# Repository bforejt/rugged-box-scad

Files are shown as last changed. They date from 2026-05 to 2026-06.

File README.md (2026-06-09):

# rugged-box-scad

Parametric, customizable rugged storage box for OpenSCAD, with a
Gridfinity-compatible variant. Forked from
[smkent/monoscad](https://github.com/smkent/monoscad) to add
non-standard Gridfinity cell sizes and stand-on-back feet.

## Project status

This is a **shared personal project** and is **work in progress**. It
is not exhaustively tested — only a small number of parameter
combinations have been exported to STL and test-printed (those that
have, have printed successfully). Many permutations of the parametric
options have never been generated, sliced, or printed.

**Caution before printing.** This fork modifies the original
`smkent/monoscad` source (see [CHANGES.md](CHANGES.md)) and bumps the
[`kennetek/gridfinity-rebuilt-openscad`](https://github.com/kennetek/gridfinity-rebuilt-openscad)
library to a newer API than upstream monoscad targets. If you customize
the box for your own use case, render it carefully and inspect the
geometry before committing filament to it.

**Testing environment.** Rendering and validation is done on Apple
silicon (macOS) with OpenSCAD **2026.06.06 (git 49366181)**. Going
forward, the latest OpenSCAD on macOS will be the primary testing
environment used by the author. Other operating systems, processor
architectures, or older OpenSCAD versions may work fine — or may not
— but they aren't actively tested.

**Reporting issues — please include repeatability details.** Issue
reports are very welcome! To help investigate effectively, please
include enough detail to reproduce what you saw. At a minimum:

- **Customizer settings used** — a screenshot of the customizer
  panel, the saved parameter-set JSON, or just a list of which values
  you changed from the file defaults
- **OpenSCAD version** — Help → About inside the app (include the
  build / git hash if shown)
- **Operating system and architecture** — e.g. "Ubuntu 24.04 on
  x86_64" or "Windows 11 on ARM"
- **What you observed** — short summary of the problem (preview
  rendered differently than expected? slicer rejected the STL? a
  printed part didn't fit?)
- **Helpful extras** — the rendered STL, a screenshot of the
  OpenSCAD preview, or the slicer's error pane all speed things up

The more reproducible the report, the faster it can be looked into.
PRs are also welcome.

## Examples

Tested, printed parameter combinations live in [`examples/`](examples/),
one subdirectory per configuration with the exported STLs alongside.
Today this is one configuration —
[`examples/43mm_gridfinity_4x3`](examples/43mm_gridfinity_4x3/) — and
the list will grow as more variants are validated. Use these as
starting points if you want a known-good configuration rather than
generating from the SCAD yourself.

Two top-level designs in [`src/`](src/):

- [`rugged-box.scad`](src/rugged-box.scad) — standalone parametric box
- [`rugged-box-gridfinity.scad`](src/rugged-box-gridfinity.scad) —
  Gridfinity-compatible variant; bottom is a Gridfinity baseplate, top
  optionally exposes Gridfinity stacking lips
- [`rugged-box-library.scad`](src/rugged-box-library.scad) — shared
  library implementing both

### Compatible Gridfinity bins

The author's primary use case for the Gridfinity variant is filling
the box with bins generated from
[ostat/gridfinity_extended_openscad](https://github.com/ostat/gridfinity_extended_openscad).
In test prints those bins have mated correctly with the box's bottom
baseplate and (when enabled) the lid's stacking-lip surface — so if
you want a known-good source for bins to drop in, that's the
companion project that's been tried here.

## Setup

```sh
git clone --recurse-submodules https://github.com/<you>/rugged-box-scad.git
# or, if already cloned without --recurse-submodules:
git submodule update --init --recursive
```

Use a recent OpenSCAD — the latest release or development snapshot is
what the author tests against (see *Testing environment* above for the
exact build). Open any `.scad` file in [`src/`](src/) directly —
relative `use`/`include` paths resolve to the submodule under
[`lib/`](lib/), so no `OPENSCADPATH` setup is needed.

## License & attribution

This project is a derivative work of two upstream projects with
different licenses. The combined work is distributed under
**CC BY-SA 4.0** ([LICENSE](LICENSE)), as required by the upstream
rugged-box code.

| Source | License | Pinned commit |
| --- | --- | --- |
| [smkent/monoscad](https://github.com/smkent/monoscad) (rugged-box and gridfinity/rugged-box subdirs) | CC BY-SA 4.0 | [`a980c0e`](https://github.com/smkent/monoscad/commit/a980c0e4a83d43316286d994b0bda67a6889529a) |
| [kennetek/gridfinity-rebuilt-openscad](https://github.com/kennetek/gridfinity-rebuilt-openscad) (submodule at [`lib/gridfinity-rebuilt-openscad`](lib/gridfinity-rebuilt-openscad)) | MIT — see [LICENSES/MIT-gridfinity-rebuilt.txt](LICENSES/MIT-gridfinity-rebuilt.txt) | [`910e22d`](https://github.com/kennetek/gridfinity-rebuilt-openscad/commit/910e22d8607fd7f5f51ad5e5cbc5287a76810bfd) |

The MIT submodule is one-way compatible into CC BY-SA 4.0; the same
arrangement is used by the upstream monoscad repo.

Original rugged-box design by Stephen Kent (smkent / bulbasaur0 on
Printables). Gridfinity-rebuilt library by Kenneth Hodson (kennetek),
based on the original Gridfinity system by Zack Freedman.

## A note on slicer warnings (cosmetic)

Slicers (PrusaSlicer, OrcaSlicer, etc.) will report **hundreds of
"errors" or "facets fixed"** when loading the exported STLs. These are
**cosmetic** and do not affect the printed result.

Two patterns produce the count:

1. **Boolean tessellation noise** — OpenSCAD's CGAL/Manifold engines
   emit a small number of zero-area (degenerate) triangles wherever
   boolean operations create coincident vertices. Every part exported
   from this project shows roughly 400 of these as a baseline; the
   exact count varies with geometry.
2. **Coplanar surface duplicates** — when two unioned solids have
   faces sitting exactly on the same plane (rather than overlapping by
   a small epsilon), the surface gets tessellated twice. This shows up
   as a handful of duplicate facets, usually on lid-mating or
   seal-groove regions.

The exported meshes are **manifold and closed** (no open edges, no
non-manifold edges) — only the degenerate/duplicate facets show up,
which every slicer auto-removes silently before slicing. The error
count is the slicer telling you what it cleaned up, not a problem with
the model.

If the count bothers you, use the slicer's built-in repair (PrusaSlicer:
right-click → *Fix through Netfabb*) to write a clean STL.

## Modifications

This is a derivative work. All modifications relative to the upstream
sources are recorded in [CHANGES.md](CHANGES.md). Entries that may be
worth contributing back to upstream are tagged `[upstream-candidate]`.

Copyright © 2026 Brian Forejt, in addition to the original copyrights
of the upstream authors.

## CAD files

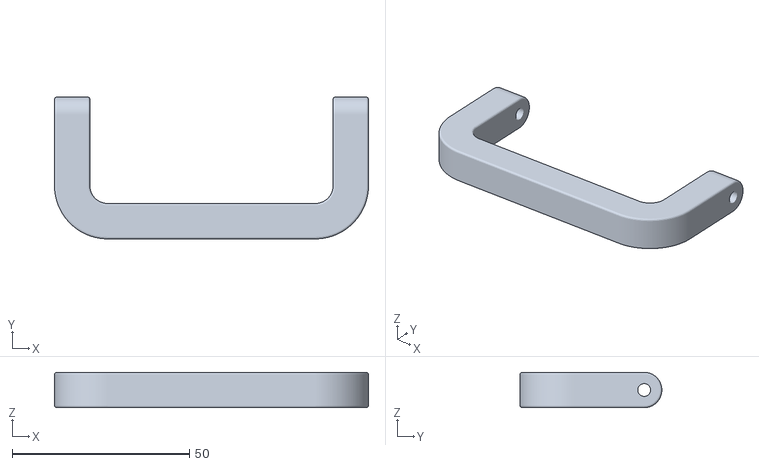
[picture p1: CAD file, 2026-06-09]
examples/43mm_gridfinity_4x3/rugged-box-gridfinity-handle.stl
88.6 x 40.0 x 10.0

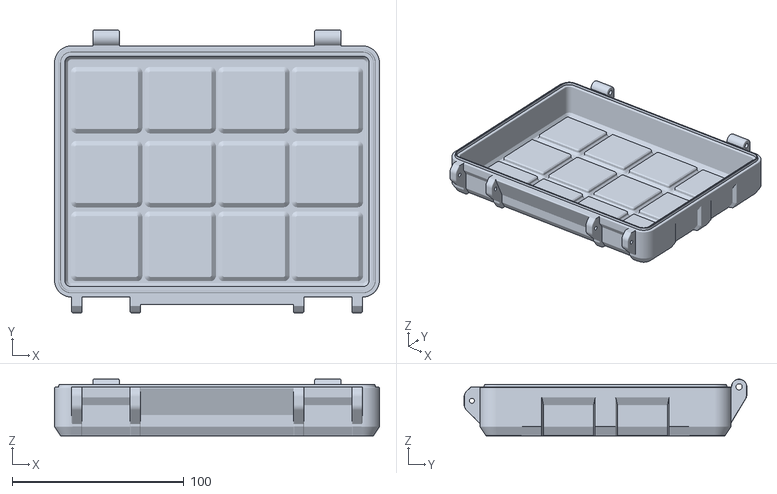
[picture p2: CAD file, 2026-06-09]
examples/43mm_gridfinity_4x3/rugged-box-gridfinity-4x3x6x3-top.stl
189.0 x 164.4 x 33.0

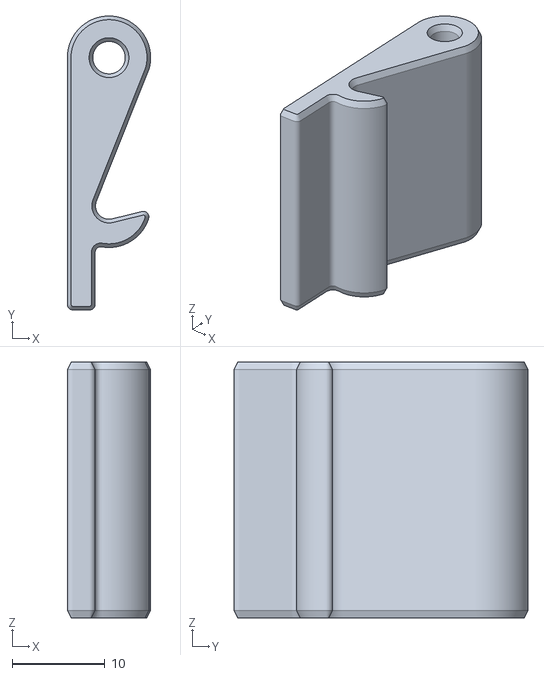
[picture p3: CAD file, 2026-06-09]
examples/43mm_gridfinity_4x3/rugged-box-gridfinity-4x3x6x3-latchx2.stl
9.00 x 31.7 x 27.6

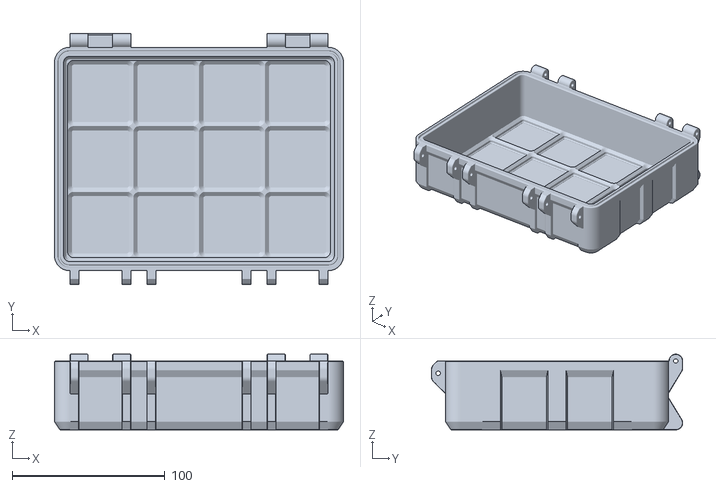
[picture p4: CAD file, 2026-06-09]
examples/43mm_gridfinity_4x3/rugged-box-gridfinity-4x3x6x3-bottom_w_handle.stl
189.0 x 164.4 x 49.5

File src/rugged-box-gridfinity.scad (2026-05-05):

/*
 * Gridfinity Rugged Storage Box, Parametric and Customizable
 * By smkent (GitHub) / bulbasaur0 (Printables)
 *
 * Licensed under Creative Commons (4.0 International License) Attribution-ShareAlike
 */

include <rugged-box-library.scad>;
include <../lib/gridfinity-rebuilt-openscad/src/core/standard.scad>;
use <../lib/gridfinity-rebuilt-openscad/gridfinity-rebuilt-baseplate.scad>;
use <../lib/gridfinity-rebuilt-openscad/src/core/base.scad>;
use <../lib/gridfinity-rebuilt-openscad/src/core/gridfinity-rebuilt-holes.scad>;
use <../lib/gridfinity-rebuilt-openscad/src/helpers/shapes.scad>;

/* [Rendering] */
// Part selection. Note: Assembled box previews show latches without chamfers for performance reasons.
Part = "assembled_open"; // ["bottom": Bottom, "top": Top, "latch": Latch, "stacking_latch": Stacking latch, "handle": Handle, "label": Label, "side-by-side": Top and Bottom side-by-side, "assembled_open": Assembled open, "assembled_closed": Assembled closed, "bottom_modifier": Bottom print modifier volume for attachment ribs, "top_modifier": Top print modifier volume for attachment ribs, "top_grid_modifier": Top print modifier volume for Gridfinity lid]

/* [Dimensions] */
// Interior side-to-side size in 42mm Gridfinity units
Width = 4; // [1:1:10]

// Interior front-to-back size in 42mm Gridfinity units
Length = 2; // [1:1:10]

// Interior bottom height in 7mm Gridfinity units
Bottom_Height = 7; // [1:1:30]

// Interior top height in 7mm Gridfinity units
Top_Height = 2; // [1:1:10]

/* [Gridfinity Features] */
Gridfinity_Base_Style = "minimal"; // [minimal: No magnet holes with minimal thickness, thick: No magnet holes but with magnet hole base thickness, enabled: Magnet holes with skeletonized baseplate, enabled_full: Magnet holes with filled baseplate]

// Add Gridfinity base stacking plates to outside of box top and bottom. Requires supports to print.
Gridfinity_Stackable = true;

// Side length of each square Gridfinity grid cell in millimeters (standard is 42)
Cell_Size = 42; // [30:0.5:50]

/* [Features] */
// Type or shape of seal to use, if desired
Lip_Seal_Type = "wedge"; // [none: None, wedge: Wedge ▽, square: Square □, "filament-1.75mm": 1.75mm Filament ○]

// Make the corners as thick as the box lip
Reinforced_Corners = true;

// Add a front grip to the box top (for boxes with two latches)
Top_Grip = true;

// Add end stops to the hinges on the box bottom
Hinge_End_Stops = true;

// Add feet at the bottom-back of the box bottom matching the hinge protrusion so the box can stand upright on its back when closed
Stand_On_Back = false;

// Add stacking latches and attachment points to the sides of the box
Stacking_Latches = true;

// Latch style
Latch_Type = "draw"; // [clip: Clip, draw: Draw]

// Add a third hinge for boxes 5U or wider
Third_Hinge = true;

// Optional handle for sufficiently wide boxes
Handle = true;

// Optional label for sufficiently wide boxes
Label = true;

// Custom text for optional label
Label_Text = "Label";

// Approximate height of text for optional label in millimeters
Label_Text_Size = 10; // [5:0.1:25]

/* [Advanced Size Adjustments] */
// Base wall thickness in millimeters for most of the box
Wall_Thickness = 3.0; // [2.4:0.1:10]

// Thickness in millimeters to add to the wall thickness for the box lip
Lip_Thickness = 3.0; // [0.4:0.1:10]

// Base thickness in millimeters of the support ribs. The latch ribs are this thick, while the hinge and side ribs are twice this thick.
Rib_Width = 6; // [1:0.1:20]

// Latch width in millimeters
Latch_Width = 28; // [5:1:50]

// Distance in millimeters between the latch hinge and catch screws which determines the latch vertical size
Latch_Screw_Separation = 16; // [5:1:40]

// Width in millimeters subtracted from latches for fit
Size_Tolerance = 0.20; // [0:0.01:1]

module __end_customizer_options__() { }

// Constants

edge_chamfer_proportion = 0.95;

border = 5;
gridfinity_height_increment = 7;

width = Width * Cell_Size + border;
length = Length * Cell_Size + border;
bottom_height = (
    Bottom_Height * gridfinity_height_increment
    + gridfinity_base_extra_height(hole=true)
);
top_height = Top_Height * gridfinity_height_increment + STACKING_LIP_HEIGHT;

corner_radius = BASE_TOP_RADIUS;

stackable_plate_offset = 3.4;
stackable_top_plate_offset = -0.8;
stackable_bottom_base_offset = -0.6;
top_base_offset = -(BASE_HEIGHT - STACKING_LIP_HEIGHT);

stacking_separation = Gridfinity_Stackable ? 1.6 : 0;

// Library overrides

function rb_color(part) = (part == "top" ? "LightSteelBlue" : "SteelBlue");

function rb_side_rib_positions() = [
    for (j = [for (i = [0:1:Length - 1]) i * Cell_Size])
    j - (Cell_Size * (Length / 2 - 0.5))
];

function rb_rear_rib_positions() = [
    for (j = [for (i = [1:1:Width - 2]) i * Cell_Size])
    j - (Cell_Size * (Width / 2 - 0.5))
];

function rb_latch_hinge_position() = (Cell_Size * (Width / 2 - 0.5));

function rb_stacking_latch_positions() = (
    Stacking_Latches
    ? [
        let (points = [
            each for (j = [
                for (i = [0:2:Length / 2 - 1]) i
            ]) (j == Length - 2 - j) ? [j] : [j, Length - 2 - j]
        ])
        for (j = [for (i = points) (i + 0.5) * Cell_Size])
        j - (Cell_Size * (Length / 2 - 0.5))
    ]
    : []
);

// Functions

function gridfinity_base_plate_magnets_enabled() = (
    (Gridfinity_Base_Style != "minimal" && Gridfinity_Base_Style != "thick")
);

function gridfinity_base_plate_magnet_height() = (Gridfinity_Base_Style != "minimal");

function gridfinity_base_plate_style() = (
    Gridfinity_Base_Style == "minimal"
        ? 0
        : Gridfinity_Base_Style == "thick"
            ? 1
            : Gridfinity_Base_Style == "enabled"
                // Use full plate instead of skeletonized for stackable top baseplate
                ? ($b_part == "top" ? 1 : 2)
                : Gridfinity_Base_Style == "enabled_full"
                    ? 1
                    : 0
);

function gridfinity_base_extra_height(hole) = (
    gridfinity_base_plate_magnet_height() ? (hole ? MAGNET_HOLE_DEPTH : 0) : 0
);

// Modules

module gridfinity_rectangle(adjust=0, height=BASE_HEIGHT * 2) {
    linear_extrude(height=height)
    rounded_square(
        [width + adjust, length + adjust],
        BASE_TOP_RADIUS,
        center=true
    );
}

function gridfinity_hole_options() = bundle_hole_options(
    refined_hole=false,
    magnet_hole=gridfinity_base_plate_magnets_enabled(),
    screw_hole=false,
    crush_ribs=true,
    chamfer=true,
    supportless=false
);

module gridfinity_baseplate(expand=false) {
    extra_depth = gridfinity_base_extra_height(hole=true);
    render(convexity=4)
    intersection() {
        linear_extrude(height=Cell_Size + extra_depth)
        square([(Width + 1) * Cell_Size, (Length + 1) * Cell_Size], center=true);
        translate([0, 0, extra_depth])
        gridfinityBaseplate(
            [Width, Length],
            Cell_Size,
            [
                expand ? ((Width + 1) * Cell_Size) : 0,
                expand ? ((Length + 1) * Cell_Size) : 0
            ],
            gridfinity_base_plate_style(),
            gridfinity_hole_options(),
            0
        );
    }
}

module gridfinity_base(w=Width, l=Length, hole=false, off=0) {
    // Pre-refactor kennetek's gridfinityBase took an `off` parameter that
    // shrank/grew the base XY dimensions. The new API has no equivalent;
    // approximate by uniformly scaling XY (Z preserved). At Cell_Size=42,
    // off=-0.2 → scale factor 0.9952 — base radius shrinks by ~0.02mm.
    scale_xy = (Cell_Size + off) / Cell_Size;
    scale([scale_xy, scale_xy, 1])
    gridfinityBase(
        [w, l],
        [Cell_Size, Cell_Size],
        hole ? gridfinity_hole_options() : bundle_hole_options()
    );
}

module gridfinity_bottom_base(hole=false) {
    intersection() {
        translate([0, 0, BASE_HEIGHT])
        mirror([0, 0, 1])
        gridfinity_base(hole=hole);
        gridfinity_rectangle(adjust=1.6);
    }
}

module rbox_interior_base(height = BASE_HEIGHT * 2) {
    intersection() {
        rbox_interior(cut_height=height);
        rbox_for_interior()
        linear_extrude(height=height)
        square([width * 2, length * 2], center=true);
    }
}

module gridfinity_baseplate_cut() {
    render()
    difference() {
        rbox_interior_base();
        rbox_for_interior()
        gridfinity_baseplate(expand=true);
    }
}
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

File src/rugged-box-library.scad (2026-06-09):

/*
 * Customizable and Parametric Rugged Storage Box
 * By smkent (GitHub) / bulbasaur0 (Printables)
 *
 * Rugged storage box library
 *
 * Licensed under Creative Commons (4.0 International License) Attribution-ShareAlike
 */

module __end_customizer_options__() { }

// Constants

$fa = $preview ? $fa : 2;
$fs = $preview ? $fs / 2 : 0.2;

// Attachment screw diameter
screw_diameter = 3; // M3

// Decrease screw hole diameter just slightly for better thread-forming fit
screw_hole_diameter_size_tolerance = -0.1;

// Widen angle of box plain ribs
plain_ribs_angle = 8;

// Extra space between box body and hinge for clearance
hinge_extra_setback = 0.2; // [0:0.1:2]
hinge_size_tolerance = 0.1;

// Box top hinge screw eyelet position fit tolerance adjustment
top_hinge_eyelet_position_tolerance = 0.1;

// Screw eyelet diameter as a proportion of screw diameter
screw_eyelet_size_proportion = 3.0; // [1.5:0.1:5]

// Depth and maximum width of lip grip
top_grip_depth = 6;
top_grip_width = 100;

// Latch size
latch_edge_radius = 0.8;
latch_body_size_proportion = 3.0; // [1.5:0.1:5]

// Stacking latch size
stacking_latch_catch_offset = -10;
stacking_latch_grip_length = 8;
stacking_latch_screw_separation = 20;

// Handle size
handle_thickness = 10;
handle_min_height = 16;
handle_max_height = 35;
handle_radius = 5;

// Label size
label_thickness = 2;
label_fit_thickness = 0.1;
label_text_thickness = 2.0;
label_holder_inset = 5;
label_holder_lip = 2;
label_holder_thickness = 2 + label_thickness + label_fit_thickness;
label_max_height = 30;

// Public modules

/*
 * Setup module
 *
 * Use this module to configure box sizing and features before rendering a part
 *
 * Arguments:
 *  - width: Interior side-to-side size
 *  - length: Interior front-to-back size
 *  - top_height: Interior top height
 *  - bottom_height: Interior bottom height
 *  - corner_radius: Interior corner radius (Reduces interior storage space)
 *  - edge_chamfer_proportion: Proportion of corner_radius to chamfer outer
 *    top/bottom edges (Reduces interior storage space)
 *  - lip_seal_type: Type of shape of seal to use, if desired:
 *      - "none": No seal
 *      - "wedge": Wedge-shaped seal
 *      - "square": Square-shaped seal
 *      - "filament-1.75mm": Seal cutout on both top and bottom for
 *          1.75mm filament
 *  - reinforced_corners: Make the corners as thick as the box lip
 *  - latch_type: Style of front latches: "clip" or "draw"
 *  - latch_count: Number of latches (1 or 2). The default of 0 determines the
 *    number of latches automatically.
 *  - top_grip: Add optional grip to front of box top
 *  - hinge_end_stops: Add optional hinge end stops to box bottom hinges
 *  - stand_on_back: Add feet to the bottom-back of the box bottom matching
 *    the hinge protrusion so the closed box can stand upright on its back
 *  - handle: Add optional handle for sufficiently wide boxes
 *  - label: Add optional label for sufficiently wide boxes
 *  - label_text: Custom text for optional label
 *  - label_text_size: Approximate label text size in millimeters
 *
 * Example:
 *
 *      box(width=100, length=50, top_height=15, bottom_height=30) {
 *          // Render box top
 *          translate([120, 0, 0])
 *          rbox_top();
 *
 *          // Render box bottom
 *          rbox_bottom();
 *      }
 */
module rbox(
    width,
    length,
    bottom_height=0,
    top_height=0,
    corner_radius=5,
    edge_chamfer_proportion=0.4,
    lip_seal_type="wedge",
    reinforced_corners=false,
    latch_type="draw",
    latch_count=0,
    top_grip=false,
    hinge_end_stops=false,
    stand_on_back=false,
    handle=false,
    label=false,
    label_text="",
    label_text_size=10
) {
    // Set base dimensions
    $b_inner_width = width;
    $b_inner_length = length;
    $b_top_inner_height = top_height;
    $b_bottom_inner_height = bottom_height;
    $b_corner_radius = corner_radius;
    $b_edge_chamfer_proportion = edge_chamfer_proportion;
    $b_lip_seal_type = lip_seal_type;
    $b_reinforced_corners = reinforced_corners;
    $b_latch_type = latch_type;
    $b_latch_count = latch_count;
    $b_top_grip = top_grip;
    $b_hinge_end_stops = hinge_end_stops;
    $b_stand_on_back = stand_on_back;
    $b_handle = handle;
    $b_label = label;
    $b_label_text = label_text;
    $b_label_text_size = label_text_size;
    // Set defaults
    $b_preview_assembled = false;
    $b_preview_box_open = false;
    rbox_size_adjustments()
    _box_rib_angle(0)
    // Render modules
    children();
}

/*
 * Advanced size adjustments setup module
 *
 * Use this module to configure advanced box sizing adjustments before rendering a part
 *
 * Arguments:
 *  - wall_thickness: Base wall thickness for most of the box
 *  - lip_thickness: Thickness to add to the wall thickness for the box lip
 *  - rib_width: Base thickness of the support ribs. The latch ribs are this
 *    thick, while the hinge and side ribs are twice this thick.
 *  - latch_width: Latch side-to-side width
 *  - latch_screw_separation: Distance between the latch hinge and catch screws
 *    which determines the latch vertical size
 *  - latch_amount_on_top: Vertical size of the latch measured from the latch
 *    hinge screw hole overlapping the top of the box, with the remainder
 *    overlapping the bottom. Set to 0 to determine automatically.
 *  - third_hinge_width: Add a third, center hinge if the box's interior is at
 *    least as wide as this value. Set to 0 to disable (default).
 *  - stacking_separation: The vertical distance between two stacked boxes.
 *    Used for stacking latch attachment placement.
 *  - size_tolerance: Size subtracted from latch and upper hinge widths for fit
 *
 * Example:
 *
 *      box(width=100, length=50, top_height=15, bottom_height=30) {
 *          rbox_size_adjustments(wall_thickness=3.0, lip_thickness=3.0) {
 *              // Render box top
 *              translate([120, 0, 0])
 *              rbox_top();
 *
 *              // Render box bottom
 *              rbox_bottom();
 *          }
 *      }
 */
module rbox_size_adjustments(
    wall_thickness=2.4,
    lip_thickness=2.0,
    rib_width=4.0,
    latch_width=22,
    latch_screw_separation=20,
    latch_amount_on_top=0,
    third_hinge_width=0,
    stacking_separation=0,
    size_tolerance=0.05
) {
    $b_wall_thickness = wall_thickness;
    $b_lip_thickness = lip_thickness;
    $b_rib_width = rib_width;
    $b_size_tolerance = size_tolerance;
    $b_latch_width = latch_width;
    $b_latch_screw_separation = latch_screw_separation;
    $b_latch_amount_on_top = _init_latch_amount_on_top(latch_amount_on_top);
    $b_third_hinge_width = third_hinge_width;
    $b_stacking_separation = stacking_separation;
    // Set computed values
    $b_total_lip_thickness = wall_thickness + lip_thickness;
    $b_lip_height = lip_thickness * 2;
    $b_edge_radius = wall_thickness / 5;
    // Set dependent values
    $b_top_outer_height = $b_top_inner_height + wall_thickness;
    $b_bottom_outer_height = $b_bottom_inner_height + wall_thickness;
    $b_outer_width = $b_inner_width + $b_total_lip_thickness * 2;
    $b_outer_length = $b_inner_length + $b_total_lip_thickness * 2;
    $b_curved_inner_width = $b_inner_width + $b_edge_radius * 2;
    $b_curved_inner_length = $b_inner_length + $b_edge_radius * 2;
    $b_outer_chamfer_horizontal = $b_edge_chamfer_proportion * $b_corner_radius;
    $b_outer_chamfer_vertical = $b_outer_chamfer_horizontal * 1.5;
    $b_hinge_screw_offset = _attachment_screw_offset();
    $b_latch_screw_offset = _attachment_screw_offset();
    children();
}

// Part modules

module rbox_top() { _box_part_setup("top") { rbox_body(); children(); } }
module rbox_bottom() { _box_part_setup("bottom") { rbox_body(); children(); } }

module rbox_for_top() { _box_part_setup("top") children(); }
module rbox_for_bottom() { _box_part_setup("bottom") children(); }

module rbox_for_interior() { translate([0, 0, $b_wall_thickness]) children(); }

module rbox_latch(placement="print") { _latch(placement); }

module rbox_stacking_latch(placement="print") { _stacking_latch(placement); }

module rbox_handle(placement="print") { _handle(placement); }

module rbox_label(placement="print") {
    rbox_for_bottom() {
        _box_label(placement);
    }
}

module rbox_body() {
    _box_color()
    _box_body();
}

module rbox_top_modifier_volume() { _box_part_setup("top") { rbox_body_modifier_volume(); } }
module rbox_bottom_modifier_volume() { _box_part_setup("bottom") { rbox_body_modifier_volume(); } }

module rbox_body_modifier_volume() {
    _box_color()
    _box_body_modifier_volume();
}

module rbox_interior(cut_height=0) {
    _box_color()
    render(convexity=4) {
        _box_extrude()
        _box_interior_shape(cut_height);
        rbox_for_interior()
        _box_center_base($b_inner_height);
    }
}
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

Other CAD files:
src/rugged-box.scad

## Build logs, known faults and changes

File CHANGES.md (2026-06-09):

# Changes

Modifications to the upstream sources in this repo. Entries tagged
`[upstream-candidate]` describe changes that could plausibly be
contributed back to monoscad as a PR.

## Baselines

- **monoscad**: [smkent/monoscad@a980c0e](https://github.com/smkent/monoscad/commit/a980c0e4a83d43316286d994b0bda67a6889529a)
  (main as of 2026-05-03), specifically:
  - `rugged-box/rugged-box.scad`
  - `rugged-box/rugged-box-library.scad` (identical to
    `gridfinity/rugged-box/rugged-box-library.scad`; one copy retained)
  - `gridfinity/rugged-box/rugged-box-gridfinity.scad`
- **gridfinity-rebuilt-openscad**: [kennetek/gridfinity-rebuilt-openscad@910e22d](https://github.com/kennetek/gridfinity-rebuilt-openscad/commit/910e22d8607fd7f5f51ad5e5cbc5287a76810bfd)
  (2025-08-31). Initial import was pinned at `0b7bf6e` (2024-01-29)
  to match Stephen's original tested API; bumped to `910e22d` on
  2026-05-03 — see migration entry below.

## 2026-05-03 — Initial import

- Imported the three rugged-box sources listed above into `src/`.
- Submoduled `lib/gridfinity-rebuilt-openscad` at the pin above.
- Adjusted `include`/`use` paths in `src/rugged-box-gridfinity.scad`
  to reference `../lib/gridfinity-rebuilt-openscad/` (Stephen's
  originals assumed the library was at `OPENSCADPATH` or in a sibling
  `gridfinity-rebuilt-openscad/` directory).

### `[upstream-candidate]` Add `Stand_On_Back` parameter and stand-feet module

Adds an optional pair of feet at the bottom-back of the box bottom,
matching the hinge protrusion, so the closed box can stand upright on
its back edge.

- `src/rugged-box-library.scad` — new `stand_on_back` arg on the `rbox`
  module, plumbed through to a new `_box_stand_feet` module which uses
  a new `_box_stand_foot_body` helper. Wired into both `assembled_open`
  and `assembled_closed` previews.
- `src/rugged-box.scad` — `Stand_On_Back` customizer parameter passed
  to `rbox`.
- `src/rugged-box-gridfinity.scad` — same wiring on the Gridfinity
  variant.

### `[upstream-candidate]` Parameterize Gridfinity cell size

Adds a `Cell_Size` customizer parameter to the Gridfinity rugged-box
(default 42 mm, range 30–50 mm in 0.5 mm steps), replacing the
hardcoded `l_grid` constant from gridfinity-rebuilt-openscad. Allows
non-standard Gridfinity grids (e.g., metric-imperial hybrids,
shrunk/expanded layouts).

- `src/rugged-box-gridfinity.scad` — `Cell_Size` parameter; all
  `l_grid` references in dimension calculations, rib positioning,
  baseplate generation, and stacking-lip generation rebound to
  `Cell_Size`.

## 2026-06-07 — Documentation: project status, examples, slicer-warnings note

Three new `README.md` sections:

- **Project status** — flags this as a shared personal project and
  work-in-progress. Notes that only a small number of parameter
  combinations have been exported to STL and test-printed; cautions
  users to inspect customized geometry before printing, particularly
  given this fork's divergence from `smkent/monoscad` and use of a
  newer `kennetek/gridfinity-rebuilt-openscad` API; invites issue
  reports for untested permutations.
- **Examples** — points at [`examples/`](examples/) as the home for
  known-good tested STL combinations (currently
  [`43mm_gridfinity_4x3`](examples/43mm_gridfinity_4x3/)).
- **A note on slicer warnings (cosmetic)** — documents why slicers
  report hundreds of "facets fixed" / "errors" on the exported STLs.
  The meshes are manifold and closed (verified via edge-incidence
  analysis); the count is OpenSCAD CGAL/Manifold boolean-tessellation
  noise (~400 zero-area triangles baseline per part) plus a small
  number of coplanar surface duplicates. Slicers auto-clean both and
  the slice output is unaffected.

Also re-exported [`examples/43mm_gridfinity_4x3/rugged-box-gridfinity-4x3x6x3-top.stl`](examples/43mm_gridfinity_4x3/rugged-box-gridfinity-4x3x6x3-top.stl)
as ASCII (was binary) — the analysis comparing baseline tessellation
counts across parts used this re-export.

Follow-up: expanded the **Project status** section with a **Testing
environment** note (Apple silicon, OpenSCAD 2026.06.06 git 49366181,
macOS as primary target — other OSes / older OpenSCAD versions may
work but aren't actively tested) and turned the issue-reports
paragraph into a checklist of repeatability details (customizer
settings, OpenSCAD version, OS/arch, summary, optional STL/screenshot)
so reports come in with enough detail to investigate.

Follow-up 2: dropped the *"OpenSCAD 2021.01 or newer recommended"*
line in the Setup section in favor of a pointer to the latest release
/ development snapshot (we don't actively test older versions, so
recommending them was misleading). Added a **Compatible Gridfinity
bins** subsection noting that
[ostat/gridfinity_extended_openscad](https://github.com/ostat/gridfinity_extended_openscad)
is the bin-generating companion project the author uses; its bins
have mated correctly with this box's bottom baseplate and stacking
lid in test prints.

## 2026-05-06 — `[upstream-candidate]` Fix stand-foot floating slivers on short boxes

`_box_stand_foot_body` computed `rib_hull_height` from
`screw_eyelet_radius`, `wall_thickness`, `rib_width`, and
`corner_radius` — independent of box height. With default `Rib_Width=6`
that yields ~38 mm. `_box_attachment_rib_cut` only clips the
inside-the-wall zone up to `wall_thickness + outer_height`, so on
boxes shorter than that, the foot's rib-shape support column
overshoots the clipper and survives as floating slivers above the box
top. Most visible on small `Bottom_Height` values; subtler but still
present on default sizes.

The hinge body doesn't have this problem because it builds at
`outer_height` and mirrors downward, so any overshoot lands below
`z=0` where the second clipper catches it. The stand foot has no
analogous downward-mirror, so the symmetry breaks.

Fix: clamp `rib_hull_height` to `$b_outer_height` in
`_box_stand_foot_body`. The clamp only affects the structural support
column inside the box wall (which would have been clipped anyway on
tall boxes); the visible eyelet bulge at low Z is unaffected. With
`Stand_On_Back=false` the geometry is byte-identical to before.

- `src/rugged-box-library.scad` — single-line `min(..., $b_outer_height)`
  wrapper around the existing formula.

## 2026-05-05 — `[upstream-candidate]` End-stop bar follows stand-foot contour

When `Stand_On_Back=true` and `Hinge_End_Stops=true` are both enabled,
the end-stop bar between the hinges grows a foot-shaped protrusion at
its bottom so its contour matches the corner stand feet on either
side. The corner feet themselves are unchanged (still aligned with the
hinge ribs above). The result reads as one continuous arch across the
back wall: feet at the corners, end-stop in the middle, all merging
into a single wide protrusion at low Z, while the end-stop bar stays
narrow at higher Z. When `Stand_On_Back=false`, the end-stop bar is
exactly the existing geometry.

- `src/rugged-box-library.scad` — `_box_hinge_rib_bottom_end_stop`
  conditionally emits an additional `_box_stand_foot_body(width=width)`
  inside its rotated frame when `$b_stand_on_back` is true. Net diff
  from main: 7 lines added.

## 2026-05-03 — `[upstream-candidate]` Migrate to current kennetek API

Bumped the `lib/gridfinity-rebuilt-openscad` submodule from `0b7bf6e`
(Jan 2024) to `910e22d` (Aug 2025), and updated
`src/rugged-box-gridfinity.scad` to match the refactored kennetek API.

**Imports** — added direct imports for the relocated symbols:
- `include` of `standard.scad` now from `src/core/`
- new `use` of `src/core/base.scad` (was in `gridfinity-rebuilt-utility.scad`)
- new `use` of `src/core/gridfinity-rebuilt-holes.scad` for `bundle_hole_options`
- new `use` of `src/helpers/shapes.scad` for `rounded_square`

**Renamed constants:**
- `h_lip` → `STACKING_LIP_HEIGHT` (3.548 → 4.4 mm)
- `h_base` → `BASE_HEIGHT` (5 → 7 mm)
- `h_hole` → `MAGNET_HOLE_DEPTH` (2.4 mm, unchanged value)
- `r_base` → `BASE_TOP_RADIUS` (4 → 3.75 mm)

The base/lip dimension drift means the rendered Z-geometry of the
Gridfinity bottom and the lid's mating top base differ slightly from
the previous version. Both halves consistently use the new constants,
so they remain self-compatible.

**Function signatures:**
- `gridfinityBaseplate(W, L, l, dx, dy, sp, magnets, sh, fitx, fity)`
  → `gridfinityBaseplate([W, L], l, [dx, dy], sp, hole_options, sh, [fitx, fity])`
  with `magnets` boolean replaced by a `bundle_hole_options(...)` bundle.
- `gridfinityBase(gx, gy, l, dx, dy, style_hole, off=, …)`
  → `gridfinityBase([gx, gy], [l, l], hole_options, …)`. The `off`
  parameter is gone; replaced with a uniform XY `scale()` wrapper that
  reproduces the inset (`-0.2mm` at the one callsite that needs it).

**Module replacement:**
- `rounded_rectangle(w, l, h, r)` → `linear_extrude(h) rounded_square([w, l], r, center=true)`.

**New helper:**
- `gridfinity_hole_options()` — local function that produces the
  `bundle_hole_options(...)` bundle, factoring out shared options
  (`crush_ribs=true`, `chamfer=true`) so both call sites stay in sync.

**Verification:** every `Part` value (12 total) renders cleanly with no
OpenSCAD errors or warnings, across all four `Gridfinity_Base_Style`
options, with `Gridfinity_Stackable` on/off, with `Stand_On_Back`
on/off, and at non-standard `Cell_Size` values (30, 38, 50). Print fit
of the new stacking-lip / top-base interface has not yet been
physically verified.

## Future work

- **Print-fit verification of the migrated lid/base interface.**
  The lid's top base uses a `scale()` workaround in place of the old
  `gridfinityBase(off=-0.2)` 0.2 mm fit-tolerance inset. Behaviorally
  equivalent in CSG, but worth a printed test before declaring final.
- **Optionally expose `bundle_hole_options(...)` flags as customizer
  parameters** (refined holes, screw holes, supportless magnet pockets,
  thumbscrew bases). Currently `gridfinity_hole_options()` hardcodes
  `crush_ribs=true, chamfer=true` and disables the rest.

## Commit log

2026-05-04 Initial setup: forked rugged-box from smkent/monoscad@a980c0e
    Adds CC BY-SA 4.0 license, MIT license snapshot for the
    gridfinity-rebuilt-openscad submodule (pinned at 0b7bf6e),
    README, CHANGES, and .gitignore. Adjusts include paths in
    rugged-box-gridfinity.scad to reference the submodule via
    relative path.
    Initial src/ also contains two pre-existing local modifications
    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
    [rugged-box-gridfinity.scad, rugged-box-library.scad, rugged-box.scad]
2026-05-04 Migrate Gridfinity variant to current kennetek API
    Bumps lib/gridfinity-rebuilt-openscad from 0b7bf6e (Jan 2024) to
    910e22d (Aug 2025) and updates rugged-box-gridfinity.scad to match.
    - Constants renamed: h_lip → STACKING_LIP_HEIGHT, h_base → BASE_HEIGHT,
    h_hole → MAGNET_HOLE_DEPTH, r_base → BASE_TOP_RADIUS. Base/lip Z
    values shift slightly with the upstream spec; both halves use the
    new constants and remain self-compatible.
    - gridfinityBaseplate signature: positional args repacked into 2D
    vectors; magnets boolean replaced by bundle_hole_options(...).
    - gridfinityBase signature: 2D vectors; off= parameter is gone, replaced
    with a uniform XY scale() wrapper that reproduces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
    [rugged-box-gridfinity.scad]
2026-05-05 End-stop bar follows stand-foot contour when both are active
    Modify _box_hinge_rib_bottom_end_stop so when $b_stand_on_back is
    true, it emits an additional _box_stand_foot_body at its low-Z end
    (inside the same rotated frame). The new foot-shaped protrusion
    visually merges with the two corner stand feet on either side, so
    the bottom-back of the box reads as one continuous arch when both
    options are active. The end-stop bar above the foot region remains
    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
    [rugged-box-library.scad]
2026-05-09 Fix floating slivers on short boxes when Stand_On_Back is active
    _box_stand_foot_body computes rib_hull_height from screw and rib/wall
    thickness — independent of box height. On boxes with Bottom_Height
    smaller than ~25mm, the foot's rib-shape support column overshoots
    the rib_cut clipper and floating slivers survive above the box top.
    Clamp rib_hull_height to $b_outer_height. The clamp only affects the
    inside-the-wall structural column (which the rib_cut would clip on
    tall boxes anyway); the visible eyelet bulge at low Z is unaffected.
    Stand_On_Back=false renders byte-identically to main.
    [rugged-box-library.scad]
2026-06-07 Document project status, examples, and slicer-warning baseline
    Add three README sections:
    - Project status: shared personal project, work-in-progress, only a
    few parameter combinations test-printed, issues welcome. Notes that
    this fork modifies smkent/monoscad and uses a newer kennetek API
    than upstream targets, so users should inspect customized geometry
    before printing.
    - Examples: points at examples/43mm_gridfinity_4x3/ as the (currently
    only) known-good tested configuration.
    - Slicer-warnings note: explains why PrusaSlicer reports hundreds of
    "facets fixed" — cosmetic boolean-tessellation noise plus a small
    number of coplanar-surface duplicates, none of which affect the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
2026-06-07 Re-export top STL in ASCII for tessellation analysis
    ASCII format makes the file directly inspectable for per-triangle
    analysis (degenerate count, coplanar duplicates, edge-incidence
    checks). See the slicer-warnings note in README for what the analysis
    showed.
    [rugged-box-gridfinity-4x3x6x3-top.stl]
2026-06-07 CHANGES.md entry for the documentation updates
    Records the README sections added in 506034a (project status,
    examples, slicer-warnings note) and the ASCII re-export of the
    4x3x6x3 top STL.
2026-06-07 Document testing environment and structured issue-report request
    Add a Testing environment paragraph (Apple silicon, OpenSCAD
    2026.06.06 git 49366181, macOS as primary target — other OSes /
    architectures / older OpenSCAD versions not actively tested) and
    expand the issue-reports paragraph into a checklist of repeatability
    details (customizer settings, OpenSCAD version, OS/arch, observation
    summary, optional STL or screenshot).
    CHANGES.md follow-up note appended to the same-day documentation
    entry.
2026-06-07 Drop stale OpenSCAD-version recommendation, add compatible-bins note
    - Setup: replaced "OpenSCAD 2021.01 or newer recommended" with a
    pointer to the latest release / development snapshot. Older
    versions aren't actively tested, so calling out 2021.01 as the
    baseline was misleading.
    - Added "Compatible Gridfinity bins" subsection pointing at
    ostat/gridfinity_extended_openscad as the bin-generating companion
    project the author uses with the Gridfinity variant. Its bins have
    mated correctly with the box bottom baseplate and stacking lid in
    test prints.
    - CHANGES.md: appended a follow-up bullet under the 2026-06-07
    documentation entry covering both above.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
2026-06-09 Re-export latchx2 and handle STLs
    Latchx2 re-rendered (smaller binary STL); handle re-exported as ASCII
    to match the top STL format used for tessellation analysis.
    [rugged-box-gridfinity-4x3x6x3-latchx2.stl, rugged-box-gridfinity-handle.stl]
2026-06-09 First pass: squared-off lid hinge foot when Stand_On_Back is active
    Adds _box_hinge_top_stand_foot — a rectangular slab unioned with each
    lid hinge eyelet (only when $b_stand_on_back is true). The slab's
    outer face is co-planar with the eyelet cylinder's outermost tangent,
    so it doesn't change the hinge's outer protrusion distance, but it
    turns what was a curved point contact into a flat rectangular contact
    patch.
    When the closed box is laid on its back face, the slab face shares
    the floor load with the bottom's stand-on-back corner feet and the
    hinge no longer wobbles.
    When Stand_On_Back=false the lid geometry is byte-identical to main
    (regression-verified by STL MD5).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
    [rugged-box-library.scad]
2026-06-09 Replace squared block with back-face rib extension
    First pass put a horizontal squared slab below the lid eyelet — sat
    too far from the lid back face to act as the foot. Replace it with a
    vertical slab on the lid's back face at each hinge group, extending
    from the eyelet position up to the lid's outer-top Z. The slab's
    outer face is co-planar with the eyelet's outermost tangent, so it
    presents a flat strip of contact along the full lid-back height when
    the closed box is laid on its back. The hinge eyelet stays a rounded
    cylinder.
    sob=false CSG byte-identical to main (regression-verified).
    [rugged-box-library.scad]
2026-06-09 Lid stand-foot: merge to lid wall + add 45° chamfer at outer corner
    - Extend the slab's inner X past the lid back wall so it fuses with
    the existing rib_shape extrusion — eliminates the V-shaped notch
    between the slab and the lid body.
    - Add a 45° chamfer (size = 2 × $b_edge_radius) at the outer-bottom
    corner of each slab, mirroring the edge chamfers used elsewhere on
    the box's outer surfaces.
    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
    [rugged-box-library.scad]
2026-06-09 Lid stand-foot: replace 45° chamfer with rounded corner
    Drop the 45° chamfer at the slab's outer-bottom corner and replace
    with a quarter-circle arc of radius = screw_eyelet_radius. This
    mirrors the bottom stand-foot's curve (its hull blends the support
    column into an eyelet-sized cylinder), so the lid foot and bottom
    foot share the same outer-edge radius and the assembled box reads as
    visually balanced when laid on the back.
    Arc sampled at 24 segments. sob=false CSG byte-identical to main.
    [rugged-box-library.scad]
2026-06-09 Narrow bottom stand-foot to match lid foot side width
    Reduce _box_stand_feet's foot width from 2 × $b_rib_width to
    $b_rib_width so the bottom corner feet line up with the lid hinge
    slabs along the back wall — when the closed box is laid on its back,
    the two halves present a roughly symmetric pair.
    sob=false CSG byte-identical to main.
    [rugged-box-library.scad]
2026-06-09 Single wide bottom stand-foot spanning the full hinge assembly
    Replace the paired corner stand-feet with one continuous foot per
    hinge group, centered, width = $b_latch_width + 2 × $b_rib_width.
    That's the outer-to-outer span of the lid hinge assembly above, so
    the bottom foot lines up directly with the lid hinge and its
    stand-on-back slabs.
    Drops the _box_attachment_rib_pair so the eyelet-hull foot body is a
    single smooth shape — no step or split between corner pieces, just
    the gentle curves around the eyelet bulge that the rest of the box
    already uses.
    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
    [rugged-box-library.scad]
2026-06-09 Narrow bottom stand-foot to match lid hinge center width
    Replace the full-assembly-span foot (40mm) with a narrower foot
    matching top_hinge_width (≈15–20mm at default rib widths). One foot
    per hinge group, centered directly beneath the hinge bodies above —
    the foot occupies just the middle portion of the assembly span, not
    the full 40mm.
    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
    [rugged-box-library.scad]
2026-06-09 Center bottom stand-foot under hinge group (drop bogus translate)
    The translate([-$b_rib_width/2, 0, 0]) was inherited from
    _box_hinge_rib_bottom where it offsets the hinge body to align with
    _box_attachment_rib_pair's positioning. With the rib_pair removed
    (single foot per group, not paired), the translate just pushed the
    foot off-center by $b_rib_width/2.
    Drop the translate and narrow the width to $b_rib_width * 2
    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
    [rugged-box-library.scad]
2026-06-09 Place a stand-foot under each bottom hinge body (rib_pair)
    Replace the single centered foot with a paired pair — one foot
    directly under each hinge body, placed via _box_attachment_rib_pair
    and the same translate the hinge_rib_bottom uses. Each foot width
    equals the hinge body width ($b_rib_width * 2), so the foot reads
    as a direct continuation of the hinge above it with no step.
    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
    [rugged-box-library.scad]
2026-06-09 Narrow bottom feet to match lid hinge side-body width
    Reduce stand-foot width from $b_rib_width*2 to $b_rib_width so each
    foot matches the lid hinge side-body and the lid stand-foot slab
    above it. The wider bottom hinge body in between produces a visible
    bulge, but the lid foot and bottom foot line up as the same column.
    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
    [rugged-box-library.scad]
2026-06-09 Single centered foot per hinge group, width = lid hinge center body
    Combine the centering fix from v8 (drop the rib_pair-positioning
    translate) with the width formula from v7 (top_hinge_width):
    - _box_attachment_placement(hinge=true) places one foot per group
    - No _box_attachment_rib_pair — single foot, not paired
    - No translate offset — foot sits on the group's centerline
    - Width = _latch_width() - 2*$b_rib_width - 2*hinge_size_tolerance
    (= top_hinge_width, matching the lid hinge center body width)
    Foot is narrower than the full hinge assembly above it but matches
    the lid hinge component at the group centerline.
    sob=false CSG byte-identical to main.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
    [rugged-box-library.scad]
2026-06-09 Move foot back to paired positions under each hinge body
    Re-apply rib_pair so each hinge body has its own foot directly
    beneath it (slid outward to the hinge body X position), at width =
    $b_rib_width (matching the lid's side hinge component).
    Geometry matches v10; v11's centered-single-foot variant is reverted
    because the foot needs to be at each hinge center, not the group
    center.
    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
    [rugged-box-library.scad]
2026-06-09 Revert bottom stand-feet to main; lid changes preserved
    Return _box_stand_feet to its original form (paired corner feet at
    width $b_rib_width * 2) — the bottom stand-foot iterations on this
    branch will be revisited later. Lid hinge stand-foot additions
    (_box_hinge_top_stand_foot and the _box_hinge_ribs_top wiring) stay
    on the branch.
    [rugged-box-library.scad]
